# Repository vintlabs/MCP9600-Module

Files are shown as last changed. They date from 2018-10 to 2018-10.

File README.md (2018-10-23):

# MCP9600-Module
MCP9600 I²C Thermocouple to Digital Module (Hardware)

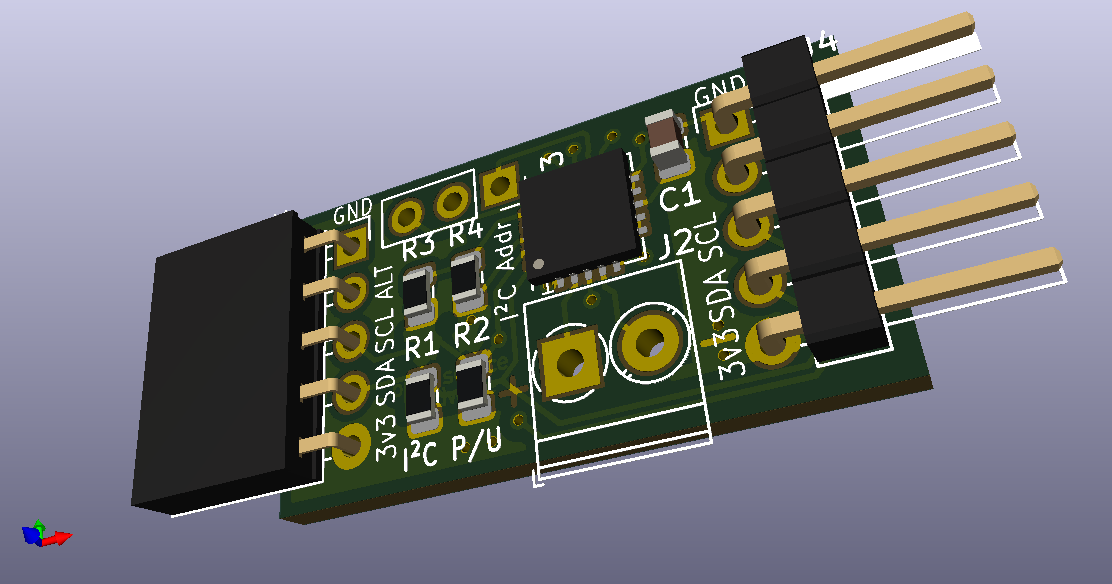
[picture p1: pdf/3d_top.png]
MCP9600 Board View


Simple module to detect temperature from a thermocouple on a Raspberry Pi (plugs in directly to the header on a Pi) or Arduino etc.
Supports thermocouple types K, J, T, N, S, E, B and R, and uses simple I²C interface. Can be run on 2.7v to 5.5v.
Board dimensions: 15x28mm (headers protrude beyond that)

There are headers on both sides of the board so that multiple boards can be connected together (being sure to use a different I2C address for each!), and there are footprints to add pullup resistors if they are required. 

Additionally, alerts can be programmed, and when plugged directly into a Raspberry Pi GPIO4 will be ALERT1, ALERT2-4 are accessible using optional header J3.

Note that as of this date, the gerbers are the Rev A prototype and the design is a bit ahead of that. (only minor edits - the Rev A board works fine)

Designed using KiCAD 5.0.0

See pdf/ directory for images and PDF of schematic.

See https://github.com/pvint/MCP9600_Pi for C code (tested on a Raspberry Pi Zero W using a type K thermocouple)

### Here are three boards in action. You can chain up to 8 boards on a single I²C bus. 
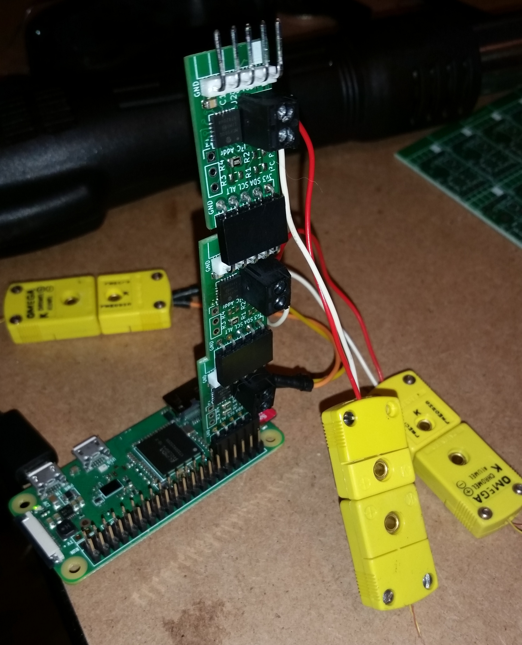
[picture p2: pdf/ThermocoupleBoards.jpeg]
MCP9600 Working Boards


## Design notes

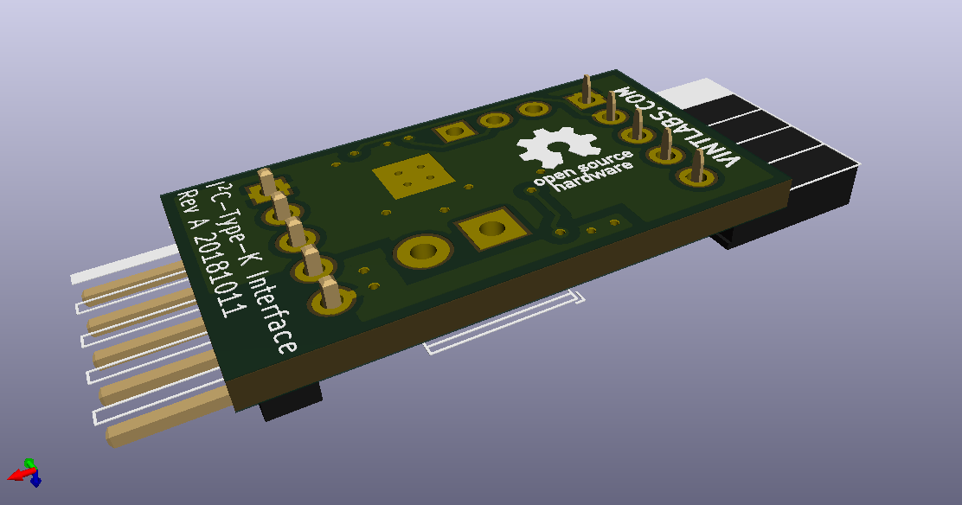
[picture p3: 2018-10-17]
pdf/3d_bottom.png

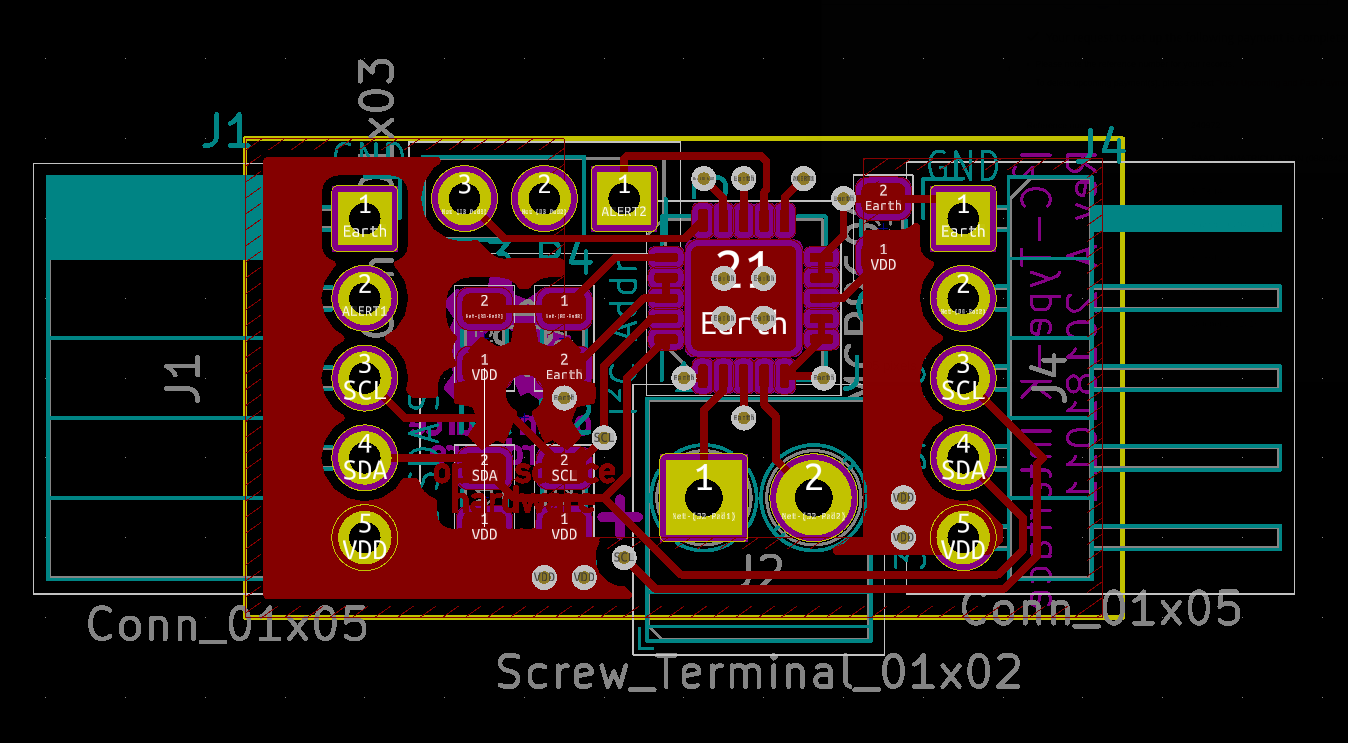
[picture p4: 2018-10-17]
pdf/pcb.png

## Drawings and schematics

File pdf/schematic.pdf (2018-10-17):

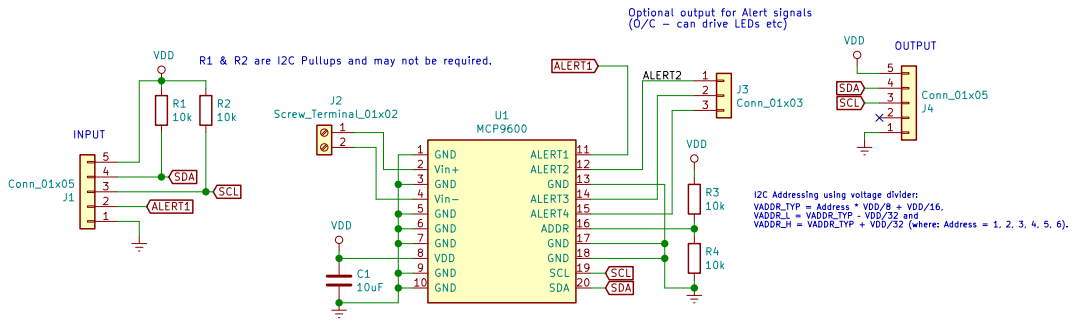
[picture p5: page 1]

Optional output for Alert signals

(O/C - can drive LEDs etc) ALERT1

I2C Addressing using voltage divider: VADDR_TYP = Address * VDD/8 + VDD/16, VADDR_L = VADDR_TYP VDD/32 and VADDR_H = VADDR_TYP + VDD/32 (where: Address = 1, 2, 3, 4, 5, 6). 1

File: I2C_Thermocouple.sch Sheet: / Paul Vint

Id: 1/1 Title: Thermocouple I2C Sensor

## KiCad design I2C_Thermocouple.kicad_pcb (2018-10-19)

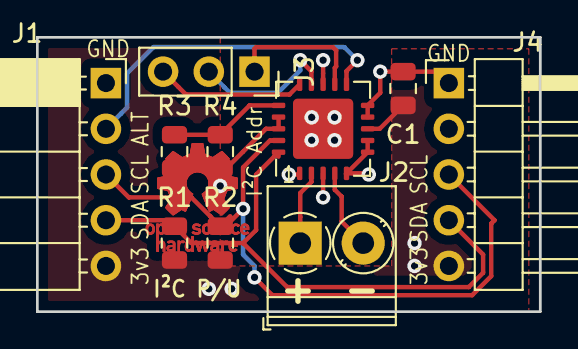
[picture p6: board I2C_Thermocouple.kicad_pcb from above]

Board: 2 copper layers, 27.9 x 15.2 mm, 10 parts (0 on the bottom side), 11 nets.

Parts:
C1: 10uF; C_0805_2012Metric
J1: Conn_01x05; PinSocket_1x05_P2.54mm_Horizontal
J2: Screw_Terminal_01x02; TerminalBlock_Phoenix_PT-1,5-2-3.5-H_1x02_P3.50mm_Horizontal
J3: Conn_01x03; PinSocket_1x03_P2.54mm_Vertical
J4: Conn_01x05; PinHeader_1x05_P2.54mm_Horizontal
R1, R2, R3, R4: 10k; R_0805_2012Metric
U1: MCP9600; MCP9600_QFN-20-1EP_5x5mm_P0.65mm_EP3.35x3.35mm

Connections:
/ALERT2: J3.1, U1.12
ALERT1: J1.2, U1.11
Earth: C1.2, J1.1, J4.1, R4.2, U1.1, U1.3, U1.5, U1.6, U1.7, U1.9, U1.10, U1.13, U1.17, U1.18, U1.21
unnamed: J2.1, U1.2
unnamed: J2.2, U1.4
unnamed: J3.2, U1.14
unnamed: J3.3, U1.15
unnamed: R3.2, R4.1, U1.16
SCL: J1.3, J4.3, R2.2, U1.19
SDA: J1.4, J4.4, R1.2, U1.20
VDD: C1.1, J1.5, J4.5, R1.1, R2.1, R3.1, U1.8

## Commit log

2018-10-17 Initial import (Only a couple changes since Rev A sent to fab shop)
    [I2C_Thermocouple-B.Cu.gbr, I2C_Thermocouple-B.Mask.gbr, I2C_Thermocouple-B.Paste.gbr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]
2018-10-17 dded images and schematic, README updates.
2018-10-19 Added +/- designations for thermocouple input
    [I2C_Thermocouple.kicad_pcb]
2018-10-20 Added image of working boards
